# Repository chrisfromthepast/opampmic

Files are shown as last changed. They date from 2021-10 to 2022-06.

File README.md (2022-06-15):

# opampmic
super simple phantom powered electret impedance converter and doug self style balanced output. As discrete JFETS are harder to come by, this circuit takes advantage of the FETS inside of a popular Op amp.

This PCB was designed to fit inside Zramo 104, and with the stock capsule, it sounds 1000 times better than the original mic. This PCB will also fit inside of MXL 603s type bodies. 

circuit designed by Jules Ryckebusch, PCB layout by me Chris Williams. I first saw this circuit here:https://www.instructables.com/OPA-Based-Alice-Microphones-a-Cardioid-and-a-Figur/

Jules has an alternate design that is impedance balanced, which is also worth a shot, as well as a version for true condensers.

I have been really happy with this little circuit.

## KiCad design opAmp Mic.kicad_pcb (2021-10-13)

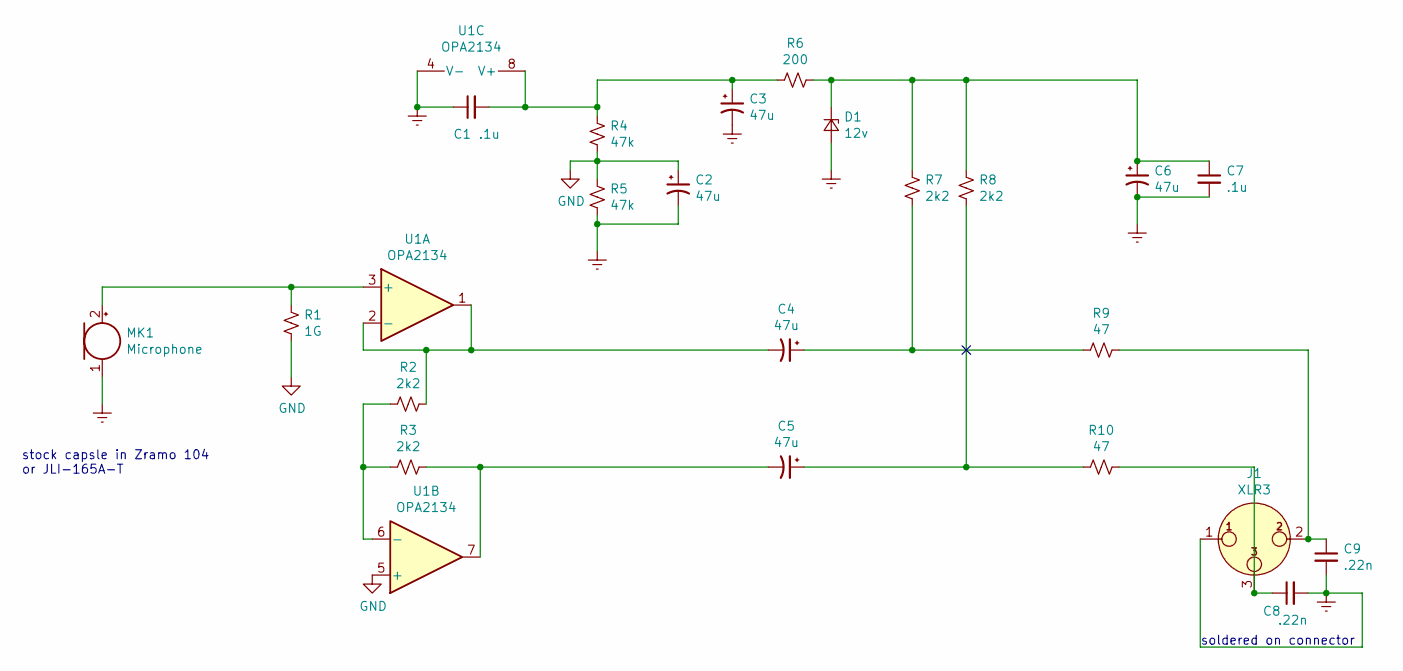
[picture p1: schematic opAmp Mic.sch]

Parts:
C1, C7: .1u; C_Disc_D3.0mm_W2.0mm_P2.50mm
C2, C4, C5, C6: 47u; CP_Radial_D6.3mm_P2.50mm
C3: 47u; CP_Radial_D4.0mm_P1.50mm
C8, C9: .22n; C_Disc_D3.0mm_W1.6mm_P2.50mm
D1: 12v; Diode_DO-35_P10mm
J1: XLR3; SolderWirePad_3x_0-8mmDrill
MK1: Microphone; PinHeader_1x2_P2.54mm_Drill1.02mm
R1: 1G; R_Axial_DIN0309_L9.0mm_D3.2mm_P25.40mm_Horizontal
R2, R3, R7, R8: 2k2; R_Axial_DIN0204_L3.6mm_D1.6mm_P2.54mm_Vertical
R4, R5: 47k; R_Axial_DIN0204_L3.6mm_D1.6mm_P2.54mm_Vertical
R6: 200; R_Axial_DIN0204_L3.6mm_D1.6mm_P2.54mm_Vertical
R9, R10: 47; R_Axial_DIN0204_L3.6mm_D1.6mm_P2.54mm_Vertical
U1: OPA2134; DIP-8_W7.62mm

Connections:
Earth: C1.1, C2.2, C3.2, C6.2, C7.2, C8.2, C9.2, D1.2 (A), J1.1, MK1.1 (-), R5.2, U1.4 (V-); also elsewhere on the board
GND: C2.1, R1.2, R4.2, R5.1, U1.5 (+); also elsewhere on the board
unnamed 2: C1.2, C3.1, R4.1, R6.2, U1.8 (V+); also elsewhere on the board
unnamed: C4.1, R7.2, R9.2
unnamed 4: C4.2, R2.1, U1.1, U1.2 (-); also elsewhere on the board
unnamed: C5.1, R8.2, R10.2
unnamed 6: C5.2, R3.1, U1.7; also elsewhere on the board
unnamed: C6.1, C7.1, D1.1 (K), R6.1, R7.1, R8.1
unnamed: C8.1, J1.3, R10.1
unnamed: C9.1, J1.2, R9.1
unnamed 10: MK1.2 (+), R1.1, U1.3 (+); also elsewhere on the board
unnamed 11: R2.2, R3.2, U1.6 (-); also elsewhere on the board

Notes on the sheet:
soldered on connector
stock capsle in Zramo 104 or JLI-165A-T

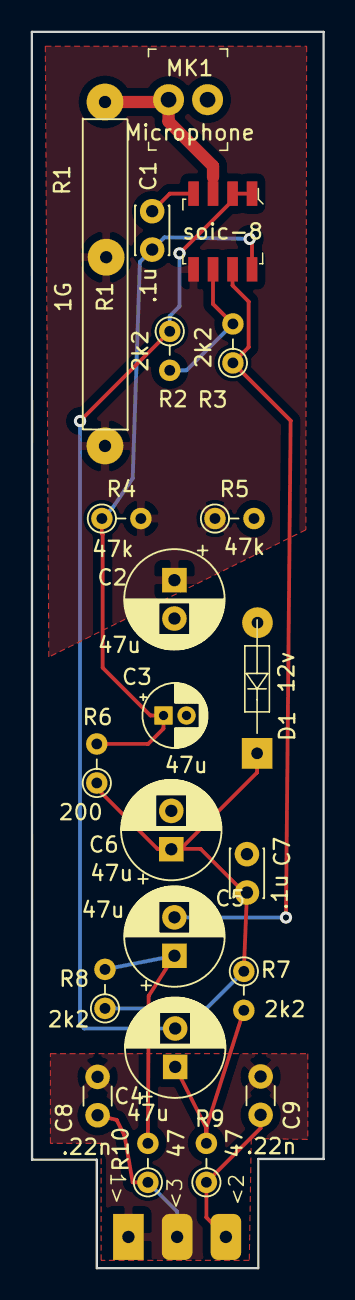
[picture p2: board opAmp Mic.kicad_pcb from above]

Board: 2 copper layers, 19.0 x 80.5 mm, 23 parts (0 on the bottom side), 12 nets.

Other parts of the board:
soic-8: SOIC-8_W5.3mm

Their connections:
Earth: soic-8.4; also elsewhere on the board
GND: soic-8.5; also elsewhere on the board
unnamed 2: soic-8.8; also elsewhere on the board
unnamed 4: soic-8.1, soic-8.2; also elsewhere on the board
unnamed 6: soic-8.7; also elsewhere on the board
unnamed 10: soic-8.3; also elsewhere on the board
unnamed 11: soic-8.6; also elsewhere on the board

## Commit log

2021-05-08 initial jlc pcb run with 2 serious errors
    [opAmp Mic-B_Cu.gbr, opAmp Mic-B_Mask.gbr, opAmp Mic-B_Paste.gbr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]
2021-05-08 added notes describing what was wrong with the original order from JLC PCB with 2 bodes, I got it working, but there are some issues with part placement that also need fixing
    [opAmp Mic.kicad_pcb]
2021-05-08 lined up capacitors in the center line remade nets after moving everything
    [opAmp Mic-B_Cu.gbr, opAmp Mic-B_Mask.gbr, opAmp Mic-B_Paste.gbr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]
2021-05-14 ready for release and board spin
    [opAmp Mic.kicad_pcb]
2021-05-14 cleaned up 1 trace for only aesthetic reasons
    [opAmp Mic.kicad_pcb]
2021-05-15 fixed some issues raised by DRC, moved some labels around
    [opAmp Mic.kicad_pcb]
2021-05-15 getting ready for an official release
    [opAmp Mic-B_Cu.gbr, opAmp Mic-B_Mask.gbr, opAmp Mic-B_Paste.gbr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]
2021-06-02 exported gerbers with updated shape and placement corrections to do: turn smt around to make high impedance path shorter
    [opAmp Mic-B_Cu.gbr, opAmp Mic-B_Mask.gbr, opAmp Mic-B_Paste.gbr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]
2021-06-02 moved op amp, changed current paths , enlarged and shortened high impedence nets
    [opAmp Mic.kicad_pcb, opAmp Mic.sch]
2021-06-11 small changes to layout, don't recall exactly
    [opAmp Mic.kicad_pcb]
2021-07-19 made the capsule ground sit on the chassis rather than the virtual ground, which solves some of the issues I had with the initial pcb run
    [opAmp Mic-B_Cu.gbr, opAmp Mic-B_Mask.gbr, opAmp Mic-B_Paste.gbr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]
2021-07-20 cleaned up some text in the schematic
    [opAmp Mic.sch]
2021-10-13 changed a few screenprints, and modified the xlr connector 1st commit using different command line on different computer, lets see how it works
    [opAmp Mic-B_Cu.gbr, opAmp Mic-B_Mask.gbr, opAmp Mic-B_Paste.gbr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]
